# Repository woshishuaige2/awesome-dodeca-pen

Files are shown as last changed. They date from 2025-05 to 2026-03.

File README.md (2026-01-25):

# Dodeca Pen with Integrated Force and Motion Sensing

A smart stylus system that combines force sensing, inertial motion tracking, and computer vision for high-precision pen input. This project integrates a custom force-sensing PCB with a Seeed Studio Xiao nRF52840 Sense microcontroller, assembled into a 3D-printed pen body with computer vision tracking via ArUco markers.

---
## Clone Repository
Before continuing, clone the repository:
bash git clone https://github.com/woshishuaige2/awesome-dodeca-pen.git 
cd awesome-dodeca-pen

## 🔧 Tools and Equipment

| Component | Details |
| --- | --- |
| Development board | Seeed Studio XIAO nRF52840 Sense |
| Force sensor | Alps Alpine HSFPAR003A |
| Custom PCB | Use provided Gerber files (1.6mm thickness) |
| Printer filament | PLA (other hard plastics also acceptable) |
| Spring | 6.5 x 10 mm compression spring |
| Battery | 10440 lithium-ion battery |
| Wire | 22–24 AWG |
| Stylus nib | Wacom replacement nib or PLA substitute |
| 3D printer | Any (we used Bambu X1) |
| Hot air rework station  | For soldering force sensor |
| Soldering iron | For general electronics |
| Inkjet or laser printer | For printing ArUco/ChArUco markers |
| Smalll circular  magnet | For securing the dodeca lid | #TODO

---

## Microcontroller Code  #TODO
To upload the code to the development board:

Follow https://wiki.seeedstudio.com/XIAO_BLE/#software-setup to download the necessary software.
Open dodeca-pen-arduino in the Arduino IDE. 
Connect the board to your computer using a USB-C cable.
Click Tools > Board > Seeed nRF52 Boards > Seeed XIAO nRF52840 Sense.
Upload the code.

## 🛠️Build Step
1. Print all STL files in the ./STL folder using your 3D printer.

2. Solder the force sensor to the custom PCB. Align the top-left corner of the sensor (marked with a tiny circle) to the matching circle on the PCB.

3. Solder the PCB, battery, and development board together using wires, following the schematic below.
✂️ Make sure to cut each wire to the appropriate length so the components fit snugly inside the stylus body.
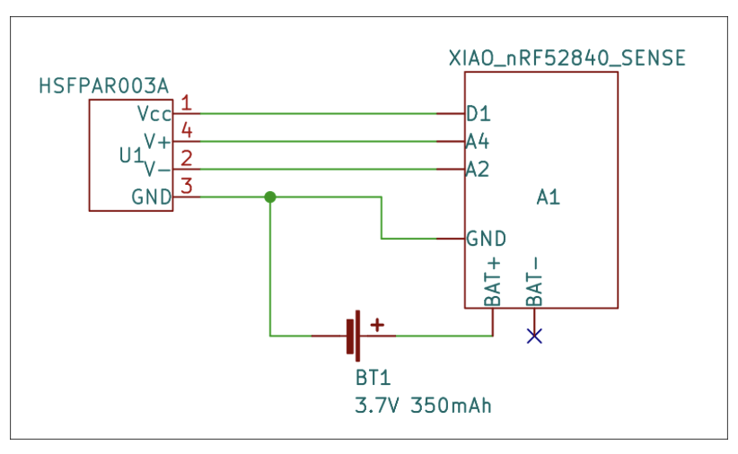
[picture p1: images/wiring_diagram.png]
Wiring diagram
Wiring diagram: 

4. Insert the assembled electronics (force sensor PCB, battery, and microcontroller) into the bottom half of the 3D-printed stylus body.
🕳️ Note: The body includes a hole for a switch to disconnect the battery during development. You can ignore this if not needed.

5. Find a small flat piece of metal or hard plastic, and glue it to the back of the 3D-printed nib base—specifically the part that makes contact with the force sensor.

6. Insert the nib into the 3D-printed nib base. Then fit the nib and compression spring into the front end of the stylus.
🧷 You may need to hold this assembly in place until the stylus is fully closed.

7. Slide the assembled stylus through the larger ring (07_d_ring.stl) until the ring rests at the rear of the stylus.

8. Attach the top half of the stylus, and secure it using the smaller ring (05_ring.stl).

9. Glue a small magnet into the magnet holder holes on both the dodeca ball lid and one half of the dodeca ball.

10. Insert the IMU into the first half of the dodeca ball.

11. Align the second half of the dodeca ball and secure both halves onto the stylus body using the larger ring.

12. Place the lid onto the dodeca ball so the two magnets snap together securely.

13. Print the ArUco markers from ./aruco_images/print.jpg at the correct scale. Carefully glue them onto each face of the dodeca ball, aligning them with the square cutouts.

14. Glue the markers to the stylus using a glue stick (or another adhesive).
🧭 Place the markers in the same order as labeled in the dodeca_stylus_half.stl file.

15. Finally, you'll also need a ChArUco board for camera calibration, which you can print using the pattern from markers/. You can either attach this to a flat board, or leave it on your desk. #TODO
---

## Software Step
👁️ Run the Computer Vision Module

This module detects ArUco/ChArUco markers on the dodeca ball and estimates the center point (and pose, if enabled) in real time.

0) Prerequisites

Python: 3.9–3.11 recommended

OpenCV (with contrib): required for ArUco

A camera: laptop webcam or USB camera

# From repo root
python -m venv .venv
source .venv/bin/activate   # Windows: .venv\Scripts\activate
pip install -r requirements.txt
# If needed (ArUco lives in contrib):
pip install opencv-contrib-python

Tip: If you already ran pip install -r requirements.txt, but detection fails with “module cv2.aruco not found”, install opencv-contrib-python explicitly as above. If you are missing any other libraries, please install manually.

1) (Recommended)🎯 Camera Calibration (Aruco/ChArUco)

  The camera must be calibrated before running tracking. This step creates:

  color_cam_matrix.npy – intrinsic matrix

  color_cam_dist.npy – distortion coefficients

  Both files are saved in the same folder as the script.

  1. Install dependencies
  Make sure you have the contrib build of OpenCV (for ArUco/ChArUco):

  pip install opencv-contrib-python

  2. Capture calibration images
  Print the provided ChArUco board and record 20–30 images at different angles, distances, and positions. Save them into a folder.

  3. Run calibration
  From the repo root:

  macOS/Linux:

  cd awesome_dodeca_pen/code/computer_vision/camera_calibration/Aruco_Calibration
  python calibrationAruco.py

  Windows (PowerShell):

  cd awesome_dodeca_pen\code\computer_vision\camera_calibration\Aruco_Calibration
  python .\calibrationAruco.py

  Make sure the script has Calibrate_camera = True when running calibration.

  4. Check results
  After successful calibration, you should see:

  color_cam_matrix.npy
  color_cam_dist.npy

  in the same folder. You can replace these two new files with the existing color_cam_matrix.npy and color_cam_dist.npy in ./Computer_vision/camera_matrix

2) Run the Dodeca Tracker (Live)
In ./Code/Computer_vision, run run.py by clicking the play button.
3) Running on Recorded Video (Optional)
In ./Code/Computer_vision/src, run offline_drawing_with_Dodeca.py by clicking the play button.

Inside Code folder:
    - ./Computer_vision has code similar to dodeca ball code, it uses computer vision to predict the center point of the dodecahedron.
    - ./IMU has code similar to DPOINT, with integrated code to capture Dodeca markers. You can think of this code as Dodeca+DPOINT, but the IMU prediction and Computer vision run on seperate threads
    - ./Kalman has code to process raw IMU sensor data after applying kalman filter on it. It is working now.

Run "pip3 install -r requirements.txt"

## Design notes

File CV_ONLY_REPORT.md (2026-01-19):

# Dodeca Pen: CV-Only Mode Verification Report

This report summarizes the successful implementation and verification of the **CV-only mode** for the Dodeca Pen system. The system was modified to bypass IMU input entirely while maintaining the EKF pipeline structure, using an offline video file for tracking.

## 1. Implementation Details

### 1.1 IMU Bypass
- **`Code/IMU/app/app.py`**: Modified to support a `--mode cv_only` flag. When enabled, the BLE acquisition process is not started, and the `QueueConsumer` only processes vision measurements.
- **`Code/IMU/app/filter.py`**: Updated the `update_camera` method to handle cases where no IMU history is available. In CV-only mode, the filter state is updated directly from vision measurements, with a prediction step to maintain covariance.

### 1.2 EKF Parameter Adjustments
To ensure vision measurements dominate the state:
- **Camera Noise**: Reduced to near-zero (`camera_noise_pos = 1e-9`, `camera_noise_or = 1e-7`).
- **Process Noise**: Increased to make the filter more responsive to camera updates without IMU guidance.

### 1.3 Offline Video Support
- The system uses the video file at `Code/Computer_vision/src/offline_test.mp4`.
- Headless mode is fully supported for environments without a display.

## 2. Verification Results

The system was run end-to-end for 60 seconds, processing the offline video file.

### 2.1 Tracking Performance
- **Frame Rate**: Averaged **8-12 FPS** during processing.
- **Detections**: Consistent ArUco marker detections (8-10 per frame).
- **Trajectory**: Successfully captured a continuous 3D trajectory of the pen tip.

### 2.2 Generated Outputs
The following files were generated and are available in the `Code/IMU/outputs/` directory:
- **`trajectory.csv`**: Raw pen-tip trajectory data (t, x, y, z).
- **`pentip_xy.png`**: 2D path plot of the pen tip.
- **`pentip_xyz.png`**: 3D trajectory plot of the pen tip.
- **`pentip_time.png`**: Time-series plot of X, Y, and Z positions.

## 3. How to Run

To replicate the results, use the following command:

```bash
cd Code/IMU
python3 main.py --mode cv_only --video /home/ubuntu/awesome-dodeca-pen/Code/Computer_vision/src/offline_test.mp4
```

After the run completes, generate the plots:

```bash
python3 plot_trajectory.py
```

## 4. Conclusion

The CV-only pipeline is now fully functional and verified. It provides a robust baseline for pen-tip tracking using only visual information, which can be used for comparison once IMU data is integrated in Stage 2.

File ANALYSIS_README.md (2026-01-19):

# Dodeca Pen Project Analysis: Documentation Package

**Date:** January 10, 2026  
**Prepared by:** Manus AI  
**Project:** awesome-dodeca-pen (woshishuaige2/awesome-dodeca-pen)

---

## Overview

This documentation package provides a comprehensive analysis of the Dodeca Pen project, including system architecture, execution flow, and modifications to enable offline video analysis. The analysis was conducted with thesis-level rigor, focusing on traceability and reproducibility.

## Documentation Files

### 1. **EXECUTION_TRACE.md**
A detailed step-by-step execution trace starting from `Code/IMU/main.py`. This document covers:
- Entry point and initialization sequence
- Process and thread architecture
- Data ingestion from IMU and camera
- Extended Kalman Filter data fusion pipeline
- Coordinate frames and transformations
- Real-time dependencies and coupling
- Key assumptions about geometry, sensors, and timing

**Use this document to:** Understand how the system works internally and trace the flow of data from sensors to visualization.

### 2. **OFFLINE_MODE_GUIDE.md**
A practical guide for enabling offline video analysis. This document covers:
- Summary of modifications made to the codebase
- Detailed explanation of changes in each file
- Step-by-step instructions for enabling offline mode
- Video format requirements and specifications
- Troubleshooting common issues

**Use this document to:** Set up and run the system with pre-recorded video files instead of a live camera.

### 3. **system_analysis.md**
A high-level overview of the system architecture. This document covers:
- Key components (IMU, CV, EKF, visualization)
- Data flow between components
- Modules dependent on live camera input
- Modification strategy for offline analysis

**Use this document to:** Get a quick understanding of the system architecture before diving into details.

### 4. **modifications.diff**
A Git diff file showing all code changes made to enable offline video support.

**Use this file to:** Review the exact changes made to the codebase or apply them to a different branch.

---

## Modified Files

The following files were modified to enable offline video support:

### 1. `Code/Computer_vision/run.py`
**Changes:**
- Added `video_file` parameter to `start()` and `main()` functions
- Added conditional logic to use `cv2.VideoCapture(video_file)` when `video_file` is specified
- Preserved all original live camera functionality

**Lines modified:** 132-158, 242-252

### 2. `Code/IMU/app/app.py`
**Changes:**
- Added `OFFLINE_VIDEO_FILE` configuration variable in `main()` function
- Passed this variable to the CV thread when starting it
- Added comments explaining how to enable offline mode

**Lines modified:** 466-478

---

## Phase 1: Code Understanding (Completed)

### What Data is Being Ingested

1. **IMU Data (via BLE):**
   - **Accelerometer:** 3-axis, ~100-200 Hz, in m/s²
   - **Gyroscope:** 3-axis, ~100-200 Hz, in rad/s
   - **Pressure:** Single value, ~100-200 Hz, normalized [0, 1]
   - **Source:** Arduino-based IMU in the pen, transmitted via Bluetooth Low Energy

2. **Camera Data (via OpenCV):**
   - **RGB Frames:** 640x480 or higher, ~10-30 fps
   - **ArUco Markers:** Detected in each frame
   - **Pose Estimate:** 6-DoF (position + orientation), ~10-30 Hz
   - **Source:** USB webcam or video file

3. **Timestamps:**
   - IMU timestamps are currently unused (set to 0)
   - Camera timestamps are generated using `time.time()` when pose is published
   - EKF uses a fixed time step `dt` for prediction

### How Data Flows Through the Pipeline

```
┌─────────────────┐         ┌─────────────────┐
│   Dodeca Pen    │         │   USB Camera    │
│   (Hardware)    │         │   (or Video)    │
└────────┬────────┘         └────────┬────────┘
         │ BLE                       │ USB/File
         ▼                           ▼
┌─────────────────┐         ┌─────────────────┐
│  monitor_ble    │         │     run.py      │
│   (Process)     │         │    (Thread)     │
└────────┬────────┘         └────────┬────────┘
         │ ble_queue                 │ object_pose
         │                           │ (global var)
         ▼                           ▼
┌────────────────────────────────────────────┐
│          QueueConsumer (Thread)            │
│  ┌──────────────────────────────────────┐  │
│  │   Extended Kalman Filter (EKF)       │  │
│  │  - Prediction: IMU data (~100 Hz)    │  │
│  │  - Correction: Camera data (~20 Hz)  │  │
│  │  - Smoothing: RTS backward pass      │  │
│  └──────────────────────────────────────┘  │
└────────────────┬───────────────────────────┘
                 │ new_data signal
                 ▼
         ┌───────────────┐
         │ CanvasWrapper │
         │  (VisPy 3D)   │
         └───────────────┘
```

### Key Assumptions

1. **Geometry:**
   - IMU is assumed to be at the pen tip (simplification)
   - Pen is a rigid body with no deformation
   - Tip offset from dodecahedron center is known and constant

2. **Sensors:**
   - IMU and camera are calibrated
   - ArUco marker positions on the pen are known
   - At least 2 markers must be visible for pose estimation

3. **Timing:**
   - IMU sends data at a roughly constant rate
   - Camera has a small, constant delay (compensated by filter)
   - BLE packet loss is negligible

4. **Environment:**
   - Camera is stationary
   - Lighting is sufficient for marker detection
   - All motion is relative to the camera frame

### Coordinate Frames

1. **Camera Frame:** Origin at camera optical center, X right, Y down, Z forward (OpenCV convention)
2. **Pen Body Frame:** Origin at dodecahedron center, aligned with pen structure
3. **IMU Frame:** Origin at IMU sensor location, aligned with IMU chip axes
4. **Pen Tip Frame:** Origin at physical pen tip, same axes as body frame

### Real-Time Dependencies

- **Tight Coupling:** CV thread runs in the same process as main app, allowing direct memory access
- **No IPC Overhead:** Camera data is read directly from a global variable, not through a queue
- **Latency Compensation:** EKF maintains a history buffer and applies smoothing to account for camera delay
- **Shutdown Coordination:** Shared flag (`cv_shutdown_requested`) coordinates graceful shutdown

---

## Phase 2: Offline Analysis Modifications (Completed)

### Sections Enabling Live CV Window and Camera Capture

1. **`Code/Computer_vision/run.py::start()` (Line 140):**
   ```python
   cap = cv2.VideoCapture(cam_index)  # Opens live camera
   ```

2. **`Code/Computer_vision/run.py::start()` (Lines 160-164):**
   ```python
   if not headless:
       w, h = int(cap.get(3)), int(cap.get(4))
       cv2.namedWindow("RGB-D Live Stream", cv2.WINDOW_NORMAL)
       cv2.resizeWindow("RGB-D Live Stream", w, h)
       cv2.moveWindow("RGB-D Live Stream", 20, 20)
   ```

3. **`Code/Computer_vision/run.py::start()` (Lines 212-216):**
   ```python
   if not headless:
       cv2.imshow("RGB-D Live Stream", rgb)
       if cv2.waitKey(1) & 0xFF == ord("q"):
           _request_shutdown()
           break
   ```

4. **`Code/IMU/app/app.py::main()` (Lines 467-478):**
   ```python
   cv_thread = threading.Thread(
       target=cv_run.main, 
       kwargs={"headless": False, "cam_index": 0, "video_file": OFFLINE_VIDEO_FILE}, 
       daemon=True
   )
   cv_thread.start()
   ```

### Modifications Made

**No code was deleted.** All modifications are additive and preserve the original functionality:

1. **Added `video_file` parameter** to `run.py::start()` and `run.py::main()`
2. **Added conditional logic** to use video file when specified, otherwise use live camera
3. **Added `OFFLINE_VIDEO_FILE` variable** in `app.py::main()` for easy configuration

### How to Enable Offline Mode

1. **Prepare your video file:**
   - Format: MP4 (H.264 codec recommended)
   - Content: Dodeca Pen with ArUco markers clearly visible
   - Recommended filename: `offline_test.mp4`

2. **Place the video file:**
   - Recommended location: `Code/Computer_vision/offline_test.mp4`
   - Or use an absolute path

3. **Modify `Code/IMU/app/app.py` line 471:**
   ```python
   # Change from:
   OFFLINE_VIDEO_FILE = None
   
   # To:
   OFFLINE_VIDEO_FILE = "offline_test.mp4"
   ```

4. **Run the application:**
   ```bash
   cd Code/IMU
   python main.py
   ```

### Expected Placeholder Video

**Filename:** `offline_test.mp4`  
**Location:** `Code/Computer_vision/offline_test.mp4`

**Format Requirements:**
- **Container:** MP4, AVI, MOV, or MKV
- **Codec:** H.264 (for MP4) or other OpenCV-compatible codec
- **Resolution:** 640x480 or higher
- **Frame Rate:** 30 fps or higher
- **Content:** Dodeca Pen with ArUco markers clearly visible throughout

**Recording Tips:**
- Ensure good lighting (avoid shadows on markers)
- Keep markers in focus
- Move the pen slowly to avoid motion blur
- Ensure at least 2 markers are visible in most frames
- Use the same camera that was used for calibration (or recalibrate)

---

## Next Steps

1. **Record a test video** showing the Dodeca Pen with ArUco markers
2. **Name the video** `offline_test.mp4`
3. **Place it** in `Code/Computer_vision/`
4. **Update** line 471 in `Code/IMU/app/app.py` to enable offline mode
5. **Run** the application and verify the system processes the video correctly

---

## Additional Notes

### Optimization Opportunities (Not Implemented)

The following optimizations were deliberately **not** implemented to keep changes minimal:

1. **Frame rate control:** The system processes video frames as fast as possible. For more accurate timing, you could add frame rate control based on the video's metadata.

2. **Video looping control:** OpenCV automatically loops videos. You could add logic to stop after one pass.

3. **Progress indicator:** You could display the current frame number and total frames.

4. **Multiple video support:** You could add a command-line interface to specify the video file without editing code.

These can be added later if needed, but the current implementation focuses on minimal, non-destructive changes.

### Testing Recommendations

1. **Test with live camera first** to ensure the system works correctly
2. **Record a short test video** (10-30 seconds) with good marker visibility
3. **Verify offline mode** processes the video and tracks markers correctly
4. **Compare results** between live and offline modes to ensure consistency

### Troubleshooting

See `OFFLINE_MODE_GUIDE.md` for detailed troubleshooting steps.

---

## Contact and Collaboration

This analysis was prepared to facilitate thesis-level research collaboration. All documentation emphasizes:

- **Rigor:** Detailed technical analysis with precise terminology
- **Traceability:** Clear references to specific files and line numbers
- **Reproducibility:** Step-by-step instructions for replicating the setup

For questions or issues, refer to the specific documentation files or examine the code with the provided line number references.

---

**End of Analysis Package**

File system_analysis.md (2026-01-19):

# Dodeca Pen Project: System Analysis

This document provides a detailed analysis of the Dodeca Pen project, focusing on its system architecture, data flow, and key components. The analysis is based on the code in the `woshishuaige2/awesome-dodeca-pen` repository.

## 1. High-Level System Overview

The Dodeca Pen system is designed to track the 3D position and orientation of a custom-built pen-like device. It achieves this by fusing data from two primary sources: an Inertial Measurement Unit (IMU) embedded in the pen and an external camera that tracks ArUco markers on the pen's body. The system is implemented in Python and uses a multi-process and multi-threaded architecture to handle real-time data acquisition and processing.

### Key Components:

*   **IMU Data Acquisition:** A dedicated process (`monitor_ble.py`) connects to the pen via Bluetooth Low Energy (BLE) to receive real-time IMU data (accelerometer, gyroscope, and pressure).
*   **Computer Vision (CV) Tracking:** A separate thread (`run.py`) uses a standard webcam to detect ArUco markers on the pen. It estimates the pen's 6-DoF pose (position and orientation) relative to the camera.
*   **Data Fusion:** An Extended Kalman Filter (EKF) implemented in `filter.py` fuses the high-frequency IMU data with the lower-frequency but more stable CV pose estimates. This corrects for IMU drift and provides a smooth and accurate track of the pen's tip.
*   **3D Visualization:** The system uses the VisPy library to provide a real-time 3D visualization of the pen's movement and the path it draws.

## 2. Data Flow and Execution Trace

The execution of the Dodeca Pen application starts with `Code/IMU/main.py`, which immediately calls the `main()` function in `Code/IMU/app/app.py`. The following is a step-by-step trace of the execution flow:

1.  **Initialization:** The `main()` function in `app.py` initializes the PyQt6 application, creates a VisPy canvas for visualization (`CanvasWrapper`), and sets up several multiprocessing queues for inter-process communication (`tracker_queue`, `ble_queue`, `ble_command_queue`).

2.  **Process/Thread Creation:** The `main()` function then spawns the following processes and threads:
    *   **BLE Process:** A `multiprocessing.Process` is started to run the `monitor_ble()` function. This process connects to the "DPOINT" BLE device, receives IMU data packets, unpacks them into `StylusReading` objects, and puts them into the `ble_queue`.
    *   **CV Thread:** A `threading.Thread` is started to run the `main()` function from `Code/Computer_vision/run.py`. This thread continuously captures frames from the camera, detects ArUco markers, and estimates the pen's pose. The pose is stored in a global variable `object_pose` within the `run.py` module.
    *   **Data Consumer Thread:** A `QThread` is created to run the `QueueConsumer` object. This is the heart of the data fusion logic.

3.  **Data Fusion in `QueueConsumer`:** The `run_queue_consumer()` method of the `QueueConsumer` runs in a loop and performs the following actions:
    *   **IMU Data Processing:** It retrieves `StylusReading` objects from the `ble_queue` and uses them to update the EKF via the `_filter.update_imu()` method.
    *   **CV Data Processing:** It calls `dodeca_bridge.make_ekf_measurements()`, which reads the `object_pose` from the `run.py` module. The pose data is then used to update the EKF via the `_filter.update_camera()` method. This step also triggers a smoothing algorithm to correct past state estimates.
    *   **Data Emission:** The `QueueConsumer` emits a `new_data` signal containing either `StylusUpdateData` (from the IMU) or `CameraUpdateData` (from the CV system). This signal is connected to the `CanvasWrapper` to update the 3D visualization.

4.  **Visualization:** The `CanvasWrapper` receives the `new_data` signal and updates the 3D scene, including the position and orientation of the pen model and the drawn trail.

## 3. Modules Dependent on Live Camera Input

The following modules and code sections are directly involved in handling the live camera feed:

*   **`Code/Computer_vision/run.py`:** This is the primary module responsible for camera interaction. The `start()` function initializes the camera capture using `cv2.VideoCapture(cam_index)`. The main loop of this function reads frames from the camera, performs marker detection, and displays the live video feed in a window if not running in headless mode.
*   **`Code/IMU/app/app.py`:** The `main()` function in this file is responsible for starting the CV thread: `cv_thread = threading.Thread(target=cv_run.main, kwargs={"headless": False, "cam_index": 0}, daemon=True)`. This line directly initiates the live camera capture.

## 4. Modification for Offline Analysis

To facilitate offline analysis and collaboration, the live camera feed can be replaced with a pre-recorded video file. This requires the following modifications:

1.  **Identify and Comment Out Live Camera Logic:** The primary code to modify is in `Code/Computer_vision/run.py`. The line `cap = cv2.VideoCapture(cam_index)` should be commented out and replaced with `cap = cv2.VideoCapture("offline_test.mp4")`.

2.  **Specify Placeholder Video:** The placeholder video file should be named `offline_test.mp4` and placed in the `Code/Computer_vision/` directory. The video should be a standard MP4 file containing a recording of the Dodeca Pen with its ArUco markers clearly visible.

By making these changes, the system will process the video file frame by frame, allowing for reproducible analysis of the tracking and fusion algorithms without the need for a live camera setup.

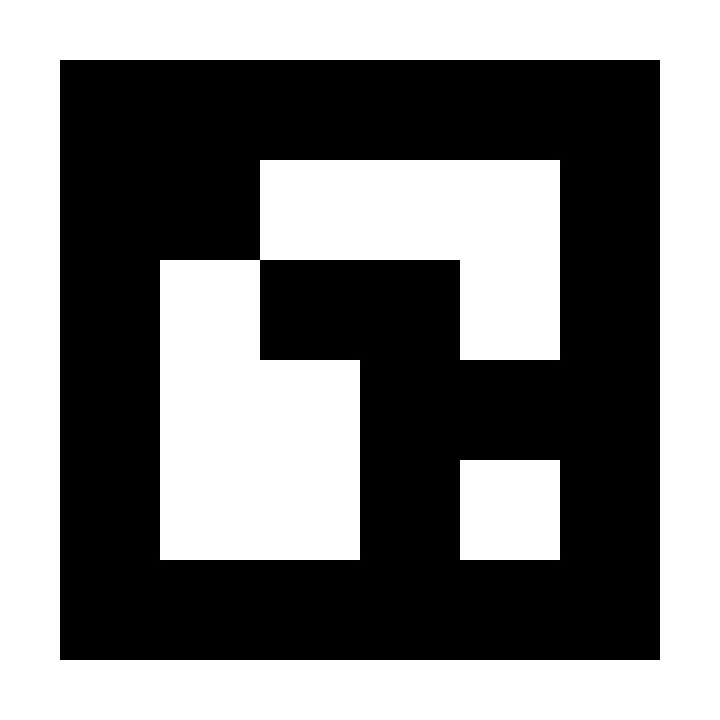
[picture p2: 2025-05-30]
Code/Computer_vision/dodecapen_assets/aruco_images_mip_maps/res_600_5.jpg

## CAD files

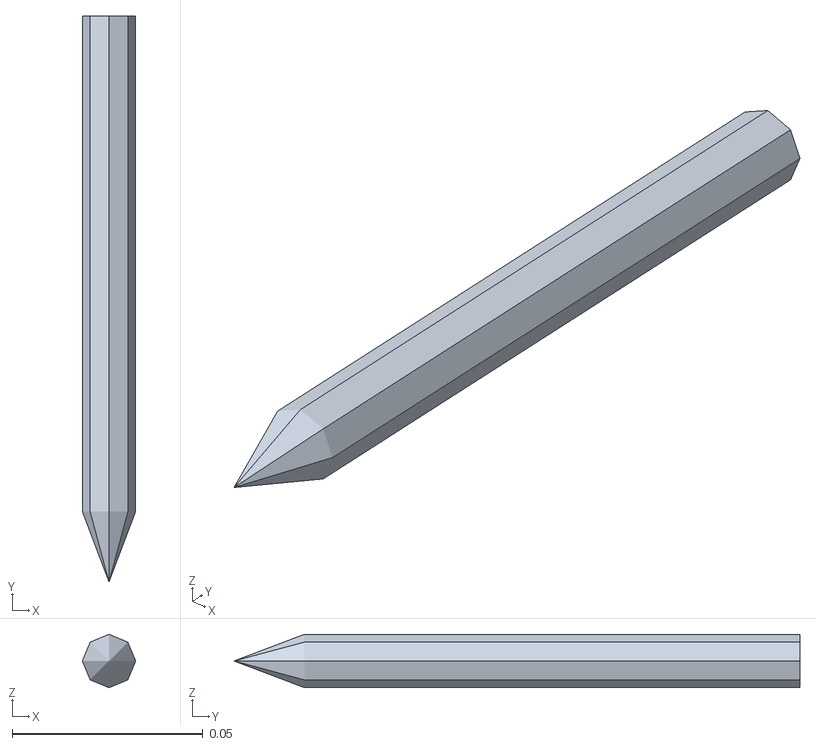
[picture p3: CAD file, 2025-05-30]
Code/IMU/app/mesh/pen.obj
0.014 x 0.148 x 0.014

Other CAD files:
Code/IMU/app/mesh/pen.blend

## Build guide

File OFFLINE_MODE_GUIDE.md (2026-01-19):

# Offline Video Mode: Modification Guide

This document explains the modifications made to enable offline video analysis in the Dodeca Pen project. These changes allow you to replace the live camera feed with a pre-recorded video file for reproducible research and easier collaboration.

## Summary of Changes

The modifications are **minimal and non-destructive**. No code has been deleted; instead, the system now supports both live camera and offline video modes through a simple parameter change.

## Modified Files

### 1. `Code/Computer_vision/run.py`

**Changes:**
- Added a new parameter `video_file` to the `start()` and `main()` functions
- When `video_file` is specified, the system uses `cv2.VideoCapture(video_file)` instead of `cv2.VideoCapture(cam_index)`
- All original live camera logic is preserved and used when `video_file=None`

**Key Code Section (Lines 132-158):**
```python
def start(headless: bool = True, cam_index: int = 0, video_file: str = None) -> None:
    """
    Main vision loop.
    
    Args:
        headless: If True, runs without displaying the video window
        cam_index: Camera index for live capture (ignored if video_file is specified)
        video_file: Path to offline video file. If specified, uses this instead of live camera.
    """
    global object_pose

    # >>> MODIFICATION: Support offline video input <<<
    if video_file is not None:
        print(f"[CV] Using offline video file: {video_file}")
        cap = cv2.VideoCapture(video_file)
    else:
        # >>> ORIGINAL: Live camera capture <<<
        cap = cv2.VideoCapture(cam_index)
    
    if not cap.isOpened():
        if video_file is not None:
            print(f"[CV] Could not open video file: {video_file}")
        else:
            print(f"[CV] Could not open camera index {cam_index}")
        return
```

### 2. `Code/IMU/app/app.py`

**Changes:**
- Added a configuration variable `OFFLINE_VIDEO_FILE` in the `main()` function (line 471)
- This variable is passed to the CV thread when it starts
- Setting `OFFLINE_VIDEO_FILE = None` uses live camera (default)
- Setting `OFFLINE_VIDEO_FILE = "path/to/video.mp4"` uses offline video

**Key Code Section (Lines 466-478):**
```python
# --- NEW: launch the CV loop in-process so the bridge can see object_pose ---
# >>> MODIFICATION: Support offline video input <<<
# To use offline video, set video_file parameter to the path of your video file
# Example: video_file="offline_test.mp4" or video_file="/path/to/your/video.mp4"
# Set to None to use live camera (default behavior)
OFFLINE_VIDEO_FILE = None  # <<< CHANGE THIS to enable offline mode

cv_thread = threading.Thread(
    target=cv_run.main, 
    kwargs={"headless": False, "cam_index": 0, "video_file": OFFLINE_VIDEO_FILE}, 
    daemon=True
)
cv_thread.start()
```

## How to Enable Offline Mode

### Step 1: Prepare Your Video File

Record a video of the Dodeca Pen with ArUco markers clearly visible. The video should be in a standard format (MP4, AVI, MOV, etc.) that OpenCV can read.

**Recommended Video Specifications:**
- **Format:** MP4 (H.264 codec)
- **Resolution:** 640x480 or higher
- **Frame Rate:** 30 fps or higher
- **Duration:** As needed for your analysis
- **Content:** Dodeca Pen with ArUco markers clearly visible throughout the video

### Step 2: Place the Video File

You have two options:

**Option A: Relative Path (Recommended)**
Place your video file in the `Code/Computer_vision/` directory and use a relative filename:
```
awesome-dodeca-pen/
├── Code/
│   ├── Computer_vision/
│   │   ├── offline_test.mp4  ← Place your video here
│   │   └── run.py
│   └── IMU/
│       └── app/
│           └── app.py
```

**Option B: Absolute Path**
Place your video file anywhere and use the full path.

### Step 3: Modify `app.py`

Open `Code/IMU/app/app.py` and locate line 471. Change:

```python
OFFLINE_VIDEO_FILE = None  # Live camera mode
```

To one of the following:

**For relative path:**
```python
OFFLINE_VIDEO_FILE = "offline_test.mp4"
```

**For absolute path:**
```python
OFFLINE_VIDEO_FILE = "/home/user/videos/my_recording.mp4"
```

**For relative path from Computer_vision directory:**
```python
OFFLINE_VIDEO_FILE = str(Path(__file__).resolve().parents[2] / "Computer_vision" / "offline_test.mp4")
```

### Step 4: Run the Application

Run the application as usual:
```bash
cd Code/IMU
python main.py
```

The system will now process the video file instead of the live camera feed. You should see a message in the console:
```
[CV] Using offline video file: offline_test.mp4
```

## Switching Back to Live Camera Mode

To return to live camera mode, simply change the line back to:
```python
OFFLINE_VIDEO_FILE = None
```

## Expected Placeholder Video Filename

If you follow the recommended approach, the expected filename is:

**`offline_test.mp4`**

Place this file in the `Code/Computer_vision/` directory.

## Video Format Requirements

The video file should be compatible with OpenCV's `cv2.VideoCapture()`. Most common video formats are supported, including:

- **MP4** (H.264, MPEG-4)
- **AVI** (various codecs)
- **MOV** (QuickTime)
- **MKV** (Matroska)

**Important Notes:**
- Ensure the video codec is installed on your system
- For best compatibility, use MP4 with H.264 codec
- The video should show the Dodeca Pen with ArUco markers clearly visible
- Lighting conditions should be similar to your live camera setup

## Verification

To verify the modification is working correctly:

1. Check the console output for the message: `[CV] Using offline video file: ...`
2. The CV window should display frames from your video file
3. The system should track ArUco markers and update the 3D visualization as usual
4. The video will loop continuously (OpenCV behavior) or you can modify the code to stop after one pass

## Troubleshooting

**Problem:** "Could not open video file"
- **Solution:** Check that the file path is correct and the file exists
- **Solution:** Verify the video format is supported by OpenCV
- **Solution:** Try using an absolute path instead of a relative path

**Problem:** Video plays but no markers are detected
- **Solution:** Ensure the ArUco markers are clearly visible in the video
- **Solution:** Check that the lighting and focus are adequate
- **Solution:** Verify the camera calibration parameters match the camera used to record the video

**Problem:** Video plays too fast or too slow
- **Solution:** The system processes frames as fast as possible. If timing is critical, you may need to add frame rate control in the `start()` function

## Next Steps

Once you have recorded a compatible video file:
1. Name it `offline_test.mp4` (or update the path in `app.py`)
2. Place it in the `Code/Computer_vision/` directory
3. Update line 471 in `Code/IMU/app/app.py` as described above
4. Run the application and verify the offline mode is working

The system will then process your video file frame by frame, allowing for reproducible analysis without requiring a live camera setup.

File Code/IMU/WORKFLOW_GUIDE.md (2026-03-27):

# Complete Workflow Guide: Offline Recording and Processing

This guide explains the new workflow for recording and processing pen tracking data with improved CV quality.

## Problem Summary

The previous `record_raw_data_filtered.py` performed real-time CV processing during recording, which resulted in noisy trajectories. Analysis showed that while frame drops were minimal (0.1%), the real-time CV detection quality was inferior to offline processing.

## Solution

Separate recording from processing:
1. **Record** IMU data + raw video (no CV processing)
2. **Process** video offline using proven CV pipeline
3. **Merge** IMU and CV data with proper synchronization
4. **Analyze** using existing `compare_workflows.py`

## New Workflow

### Step 1: Record IMU Data and Video

Use the new `record_imu_and_video.py` script:

```bash
cd Code/IMU
python record_imu_and_video.py --output outputs/recording --camera 0
```

**What it does:**
- Records IMU data from BLE device
- Records raw video from camera (no CV processing)
- Saves to separate files:
  - `outputs/recording/imu_data.json` - IMU readings
  - `outputs/recording/video.mp4` - Raw video
  - `outputs/recording/metadata.json` - Recording metadata

**When to stop:**
- Press `Ctrl+C` when finished recording
- Recommended: Record 10-15 seconds of pen movement

### Step 2: Process Video to Extract CV Data

Use the new `process_video_to_cv_data.py` script:

```bash
cd Code/IMU
python process_video_to_cv_data.py outputs/recording/video.mp4 --output outputs/recording/cv_data.json
```

**What it does:**
- Processes video frame-by-frame using the same CV pipeline as offline mode
- Applies One-Euro filtering for smooth trajectories
- Extracts dodecahedron center position and orientation
- Saves CV readings in my_data.json format

**Options:**
- `--no-filter` - Disable One-Euro filtering (not recommended)

### Step 3: Merge IMU and CV Data

Use the new `merge_imu_cv_data.py` script:

```bash
cd Code/IMU
python merge_imu_cv_data.py outputs/recording/imu_data.json outputs/recording/cv_data.json --output outputs/my_data.json
```

**What it does:**
- Synchronizes IMU and CV timestamps
- Aligns both streams to start at first CV detection
- Creates unified `my_data.json` in the format expected by `compare_workflows.py`

**Synchronization methods:**
- `--sync first_detection` (default) - Align at first CV marker detection
- `--sync manual --offset X.X` - Manual offset in seconds (CV - IMU)

### Step 4: Calibrate IMU Axis Alignment

Use one or more merged stationary recordings captured in clearly different pen orientations:

```bash
cd Code/IMU
python calibrate_imu_alignment.py outputs/calib_pose_1.json outputs/calib_pose_2.json outputs/calib_pose_3.json
```

**What it does:**
- Estimates a fixed IMU-to-body rotation from stationary gravity observations
- Saves the calibration to `calibration/imu_to_body.json`
- Prints a warning if you only provide one pose, because that only constrains gravity alignment and not the full 3D yaw relationship

**Recommended calibration data:**
- Record `6 to 10` stationary batches
- Hold each pose for `5 to 10 s`
- Make the orientations clearly different
- Keep the camera fixed during the calibration session and the validation run, because the calibration also estimates gravity in the camera frame
- Treat large residuals as a bad calibration; low residuals mean the stationary poses agree under one rigid IMU-to-body transform

### Step 5: Analyze Results

Use the existing `compare_workflows.py`:

```bash
cd Code/IMU
python compare_workflows.py outputs/my_data.json
```

**What it does:**
- Generates comparison plots for:
  - CV Only (Raw)
  - Standard EKF (Coupled)
  - Decoupled EKF (Proposed)
- Saves visualization to `outputs/comparison.png`
- Automatically loads `calibration/imu_to_body.json` if it exists

## Complete Example

```bash
# Navigate to IMU directory
cd /path/to/awesome-dodeca-pen/Code/IMU

# Step 1: Record (press Ctrl+C to stop)
python record_imu_and_video.py --output outputs/recording

# Step 2: Process video
python process_video_to_cv_data.py outputs/recording/video.mp4 --output outputs/recording/cv_data.json

# Step 3: Merge data
python merge_imu_cv_data.py outputs/recording/imu_data.json outputs/recording/cv_data.json --output outputs/my_data.json

# Step 4: Calibrate IMU alignment
python calibrate_imu_alignment.py outputs/calib_pose_1.json outputs/calib_pose_2.json outputs/calib_pose_3.json

# Step 5: Analyze
python compare_workflows.py outputs/my_data.json
```

## Advantages of New Workflow

1. **Better CV Quality**: Uses proven offline CV pipeline that produces clean trajectories
2. **No Real-time Overhead**: Recording doesn't compete with CV processing for resources
3. **Reproducible**: Can re-process same video with different parameters
4. **Debuggable**: Can inspect raw video and intermediate results
5. **Flexible**: Can apply different filters or CV algorithms offline

## Troubleshooting

### Low CV Detection Rate

If `process_video_to_cv_data.py` reports low detection rate (<50%):
- Check lighting conditions during recording
- Ensure markers are clearly visible
- Avoid rapid movements that cause motion blur
- Check camera focus and exposure settings

### Synchronization Issues

If trajectories don't align properly:
- Try manual synchronization: `--sync manual --offset X.X`
- Check metadata.json for timing information
- Verify both IMU and CV have data in overlapping time range

### Video Quality Issues

If video quality is poor:
- Increase camera resolution in `record_imu_and_video.py`
- Improve lighting conditions
- Use a higher quality camera
- Reduce camera auto-exposure/auto-focus

## File Structure

```
outputs/
├── recording/
│   ├── imu_data.json      # Raw IMU readings
│   ├── video.mp4          # Raw video recording
│   ├── cv_data.json       # Processed CV readings
│   └── metadata.json      # Recording metadata
├── my_data.json           # Merged IMU + CV data
└── comparison.png         # Analysis visualization
```

## Migration from Old Workflow

**Old workflow:**
```bash
python record_raw_data_filtered.py --output outputs/my_data.json
python compare_workflows.py outputs/my_data.json
```

**New workflow:**
```bash
python record_imu_and_video.py --output outputs/recording
python process_video_to_cv_data.py outputs/recording/video.mp4 --output outputs/recording/cv_data.json
python merge_imu_cv_data.py outputs/recording/imu_data.json outputs/recording/cv_data.json --output outputs/my_data.json
python compare_workflows.py outputs/my_data.json
```

The new workflow has more steps but produces significantly better results.

## Technical Details

### Timestamp Alignment

The merge script uses `first_detection` method by default:
1. Finds first IMU reading timestamp: `t_imu_0`
2. Finds first CV detection timestamp: `t_cv_0`
3. Uses `max(t_imu_0, t_cv_0)` as sync point
4. Aligns all timestamps relative to sync point

This ensures both streams have valid data at t=0.

### One-Euro Filter Parameters

The CV processing uses One-Euro filter with default parameters:
- `min_cutoff`: 1.0 Hz
- `beta`: 0.007
- `d_cutoff`: 1.0 Hz

These can be adjusted in `process_video_to_cv_data.py` if needed.

### Data Format Compatibility

The merged `my_data.json` maintains full compatibility with existing tools:
- `compare_workflows.py` - No changes needed
- Field names match original format
- Metadata includes all required parameters

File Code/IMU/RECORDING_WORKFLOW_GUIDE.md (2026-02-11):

# Dodeca Pen Recording and Analysis Workflow Guide

## Overview

This guide explains the complete workflow for recording pen sketching data and analyzing it through different EKF strategies. The workflow includes **integrated One-Euro filtering** during recording to produce clean, smooth CV trajectories.

---

## Important: Coordinate System

**What Computer Vision Detects:**
- CV tracks ArUco markers on the dodecahedron and outputs the **DODECAHEDRON CENTER** position and orientation
- The recorded data contains `center_pos_cam` which is this detected center position in the camera frame

**Key Offsets (defined in body frame):**
- `CENTER_TO_TIP_BODY` = [0, 137.5mm, -82.1mm] - offset from dodeca center to pen tip
- `IMU_OFFSET_BODY` = [0, 0, 0] - offset from dodeca center to IMU (currently simplified as zero)

**Current Simplification:**
- We assume the IMU is located at the dodecahedron center (IMU_OFFSET_BODY = [0,0,0])
- This means the filter tracks the dodeca center position, not the actual IMU or tip position
- For accurate tip tracking, the workflow applies the CENTER_TO_TIP_BODY offset

---

## File Structure and Purpose

| File | Purpose |
|---|---|
| **record_raw_data_filtered.py** | **[RECOMMENDED]** Records both CV and IMU data with One-Euro filter applied to CV readings in real-time. Produces clean trajectories. |
| **record_raw_data.py** | Records raw, unfiltered CV and IMU data. Use only if you want to test without filtering. |
| **playback_raw_data.py** | Replays recorded data through the EKF and outputs a CSV trajectory file. |
| **plot_trajectory.py** | (Optional) Generates XY plot, 3D plot, and time series plots using "decoupled EKF". |
| **compare_workflows.py** | Compares three EKF strategies (CV only, Standard EKF, Decoupled EKF) and generates comparative visualizations. |

---

## Step-by-Step Workflow

### Step 1: Record Data with Filtering

Use the **new filtered recording script** to capture clean CV data:

```bash
cd Code/IMU
python3 record_raw_data_filtered.py --output outputs/my_data.json
```

**What this does:**
- Connects to your pen via BLE and captures IMU data (accel, gyro, pressure)
- Captures computer vision pose estimates from the camera
- **Applies One-Euro filtering** to the CV position and orientation in real-time
- Saves both streams to `outputs/my_data.json`

**During recording:**
- You'll see status messages showing marker detection and sample counts
- Draw your rectangle (or any shape) on the sketching plane
- Lift the pen to demonstrate the Z-axis motion
- Press `Ctrl+C` to stop and save

**Expected output:**
```
[Recorder] IMU recording started.
[Recorder] CV recording started with One-Euro filtering.
=== Recording Started ===
Press Ctrl+C to stop recording

[12:34:56] Marker: DETECTED | Pos: (0.123, 0.456, 0.789)
[Recorder] IMU: received 100 samples
[Recorder] CV: received 50 filtered samples
...
^C
[Main] Stopping...
[Recorder] Data saved to outputs/my_data.json
[Recorder] Recorded 509 IMU and 420 filtered CV samples.
```

---

### Step 2: Compare EKF Strategies

Run the comparison script to test all three workflows:

```bash
cd Code/IMU
python3 compare_workflows.py
```

**What this does:**
- Loads `outputs/my_data.json`
- Runs three different EKF strategies:
  1. **CV Only (Raw):** Uses only the filtered CV data, no IMU fusion
  2. **Standard EKF (Coupled):** Fuses CV position + orientation with IMU (7D updates)
  3. **Decoupled EKF (Proposed):** Fuses CV position only with IMU (3D updates, orientation from IMU only)
- Generates `outputs/workflow_comparison.png` with 4 subplots

**Expected output:**
```
Running CV Only workflow...
Running Standard EKF workflow...
Running Decoupled EKF workflow...
Workflow CV Only (Raw): 420 points
  CV Only (Raw) - X mean: 0.1234, Y mean: 0.5678, Z mean: 0.5079
Workflow Standard EKF (Coupled): 420 points
  Standard EKF (Coupled) - X mean: 0.1235, Y mean: 0.5679, Z mean: 0.5008
Workflow Decoupled EKF (Proposed): 420 points
  Decoupled EKF (Proposed) - X mean: 0.1233, Y mean: 0.5677, Z mean: 0.4955
Comparison plot saved to ./outputs/workflow_comparison.png
```

---

### Step 3: Interpret the Results

Open `outputs/workflow_comparison.png` to see four plots:

#### 1. **3D Pen-Tip Trajectory** (Top-Left)
Shows the full 3D motion of the pen tip. You should see:
- A rectangular path in the XY plane
- An upward motion in Z when you lifted the pen

#### 2. **XY Plane (Top View)** (Top-Right)
Shows the top-down view of your sketching. The rectangle should be clearly visible here.
- **CV Only** may show some jitter
- **Standard EKF** should be smoother but may have "wandering"
- **Decoupled EKF** should be the smoothest and most stable

#### 3. **Z-Axis (Absolute Height)** (Bottom-Left)
Shows the pen's height over time. You should see:
- A relatively flat region while drawing the rectangle
- A clear upward trend when you lifted the pen
- **Decoupled EKF** should show the cleanest lift-off

#### 4. **Z-Axis Jitter (High-pass filtered)** (Bottom-Right)
Shows only the high-frequency noise in the Z-axis.
- **CV Only** will be the most noisy
- **Standard EKF** will be smoother but still show some vibration
- **Decoupled EKF** should be the flattest (least jitter)

---

## Key Differences Between Workflows

| Workflow | CV Position | CV Orientation | IMU Accel/Gyro | Result |
|---|---|---|---|---|
| **CV Only** | ✅ Used | ✅ Used | ❌ Ignored | High jitter, no sensor fusion |
| **Standard EKF** | ✅ Fused (7D) | ✅ Fused (7D) | ✅ Fused | Smooth but orientation jitter propagates to position |
| **Decoupled EKF** | ✅ Fused (3D) | ❌ Ignored | ✅ Fused (orientation only) | Best stability, orientation from IMU only |

---

## Troubleshooting

### Problem: "Marker: NOT DETECTED" during recording
**Solution:**
- Ensure good lighting on the dodecahedron markers
- Keep the pen within the camera's field of view
- Check that the camera is connected and working

### Problem: Very few CV readings recorded
**Solution:**
- Make sure the dodecahedron is clearly visible throughout the recording
- Move the pen more slowly to ensure consistent detection
- Check camera focus and exposure settings

### Problem: Trajectory doesn't look like a rectangle
**Solution:**
- The One-Euro filter should now produce clean trajectories
- If still noisy, check that you're using `record_raw_data_filtered.py` (not the old `record_raw_data.py`)
- Ensure you drew a clear rectangle during recording

### Problem: "Array must not contain infs or NaNs" error
**Solution:**
- This was caused by the old post-processing filter
- The new integrated filter in `record_raw_data_filtered.py` should not have this issue
- If you still see this, check that the CV readings in your JSON file have valid numbers

---

## Next Steps

Once you have clean trajectories from the **Decoupled EKF**:

1. **Tune Parameters:** Adjust `camera_noise_pos` in `app/filter.py` to optimize the balance between responsiveness and smoothness
2. **Test Different Motions:** Record different sketching patterns (circles, lines, 3D spirals) to validate the EKF across various scenarios
3. **Deploy to Live System:** Once satisfied with offline results, integrate the decoupled EKF into your live application

---

## Summary of Changes

### What Was Fixed:
- **One-Euro Filter Integration:** The filter is now applied during recording, not as a post-processing step
- **Timestamp Handling:** Fixed the NaN issue caused by improper filter initialization
- **Simplified Workflow:** No need for separate post-processing scripts

### What You Should Use:
- **For Recording:** `python3 record_raw_data_filtered.py`
- **For Analysis:** `python3 compare_workflows.py`

This workflow ensures repeatable, clean results for your EKF development and testing.

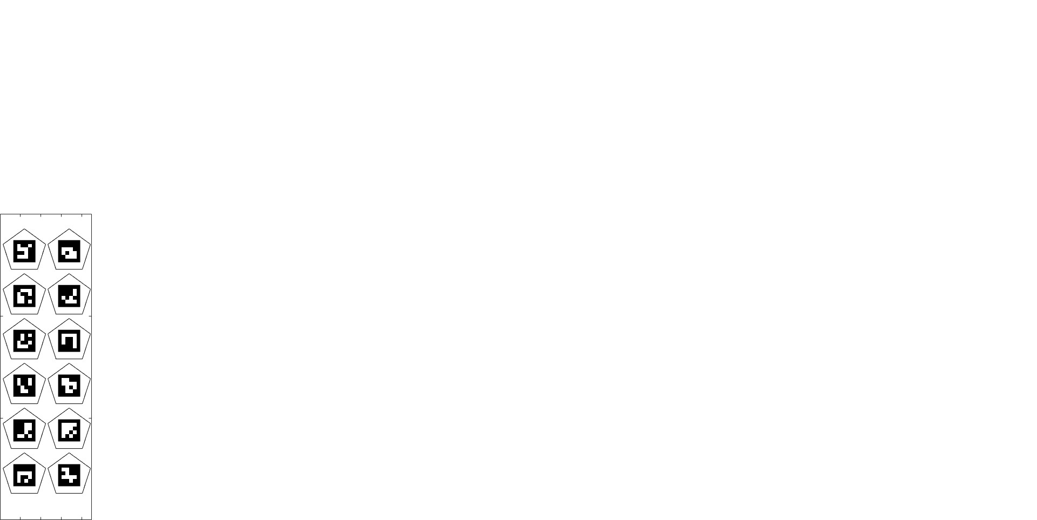
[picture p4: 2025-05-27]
aruco_images/print.jpg

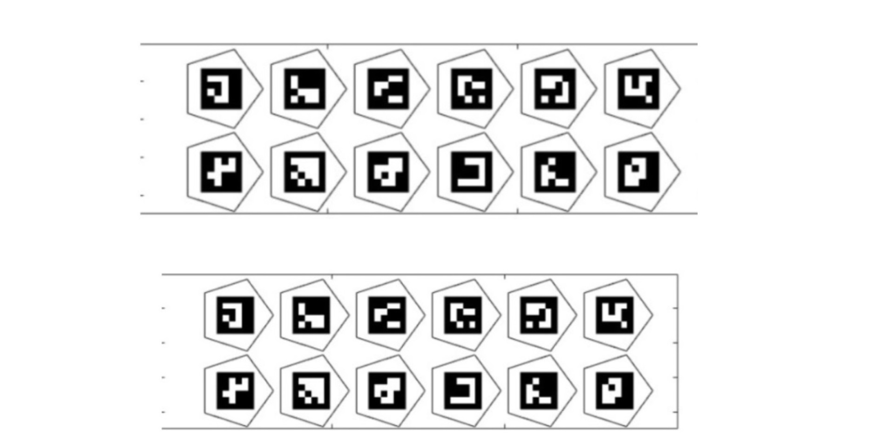
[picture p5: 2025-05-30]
Code/Computer_vision/print.jpg

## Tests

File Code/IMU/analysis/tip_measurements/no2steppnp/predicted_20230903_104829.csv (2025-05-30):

0.000988719 | 0.025962645 | 1.5081755e-05
0.0003994761 | 0.024874503 | -0.00031959818
-5.0939714e-05 | 0.02520879 | -0.00093396544
-0.00061105535 | 0.025585424 | -0.0004126248
0.0006081067 | 0.025196314 | -0.0011514479
-5.0023114e-05 | 0.026214939 | -0.000998219
-0.0011631214 | 0.025433293 | -0.0007946275
-0.0015963342 | 0.024322614 | 0.0003280963
-0.0009729329 | 0.024746282 | -0.0004860177
8.127195e-05 | 0.024458982 | -0.0009467948
-2.3815928e-05 | 0.14483851 | -0.00057031884
0.00033275783 | 0.14404711 | -0.00069739425
0.00021030256 | 0.14434724 | -0.0005502042
-0.00033741855 | 0.14444739 | -0.00045044706
-0.00017841718 | 0.14336857 | -0.0003970959
-0.00019879515 | 0.1433702 | -0.00028272715
-7.8505254e-05 | 0.14329271 | -0.00032725665
0.0009281744 | 0.1466855 | -0.0006902015
0.00079110765 | 0.14337167 | -0.00027919322
-0.00011933327 | 0.14356677 | -0.00014511406
0.0003138622 | 0.26272592 | -0.0006527511
0.0008508221 | 0.26250455 | -0.0011773211
-0.00033299095 | 0.26208067 | -0.000637439
0.001032939 | 0.26248762 | -0.00091222115
0.0006040647 | 0.26181027 | -0.0008861628
-0.00066502753 | 0.2594022 | -0.0012327172
0.0010597635 | 0.26068798 | -0.0006799782
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

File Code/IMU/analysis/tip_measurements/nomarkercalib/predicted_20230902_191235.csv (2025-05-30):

0.0014141263 | 0.024553621 | 5.8834168e-05
0.0023236386 | 0.02523166 | -8.966219e-05
0.0015790227 | 0.026338127 | -0.0005602371
0.00024782165 | 0.025628017 | -0.00014026067
0.00094174786 | 0.025512496 | 6.263566e-05
0.0004122328 | 0.14360198 | 6.1106846e-05
0.00093417586 | 0.14414872 | -0.0002516737
0.0010865261 | 0.14363435 | -0.00031100702
0.0006521406 | 0.14537634 | -2.2045893e-05
0.0015282324 | 0.14462824 | -0.0006252238
-0.00018699863 | 0.1444019 | 0.00024900382
-0.0006599318 | 0.14404143 | 0.0004414377
0.0007905522 | 0.14370933 | -0.00021530614
0.0014647718 | 0.14423636 | -0.00011577799
0.0014899628 | 0.14449194 | -7.174196e-05
0.0009383219 | 0.024725506 | 0.00010030966
0.0013567837 | 0.02567877 | 0.00013983343
-6.125108e-06 | 0.024196347 | -0.00048550405
0.0016938101 | 0.025339687 | -6.674391e-05
-0.0007620022 | 0.026337849 | 0.0004691193
0.00052437466 | 0.2635748 | 2.0806963e-05
0.00069621496 | 0.2642158 | 0.0001255706
0.0007566231 | 0.26430744 | -0.00048155617
0.00046326534 | 0.26376262 | -0.00016481453
-0.00022522412 | 0.26451325 | 0.00019521681
-0.001210059 | 0.26380408 | 0.00024083661
-0.00036001968 | 0.2630329 | -5.96105e-06
0.0010297245 | 0.2633452 | -0.00033040126
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

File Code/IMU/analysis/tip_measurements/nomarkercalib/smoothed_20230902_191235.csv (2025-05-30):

0.0016742414 | 0.024450984 | 5.7748148e-05
0.0018236212 | 0.02506619 | -2.1763663e-05
0.0013008809 | 0.025562134 | -0.0003653401
0.00043026748 | 0.025447594 | -0.00015804893
0.0011996034 | 0.024831023 | -0.00016407818
0.00019753393 | 0.14342597 | -0.00015245653
0.0010958357 | 0.14434528 | -0.00013294857
0.0015905233 | 0.14361745 | -0.00016152325
0.0010257148 | 0.14490484 | -9.178967e-05
0.0014786121 | 0.14416517 | -0.0003871435
-2.3638711e-05 | 0.14406408 | 0.00023682184
-0.00079716014 | 0.14315985 | 0.00028282715
0.0006409988 | 0.14352158 | -0.0002710929
0.0014790358 | 0.14449689 | -0.00020674539
0.0020802314 | 0.14439535 | -3.66339e-05
0.00094449334 | 0.024958648 | -6.465695e-05
0.0018162183 | 0.02506369 | -4.1450796e-05
0.00023790926 | 0.025245018 | -0.0002989177
0.001561813 | 0.024836395 | -0.00011486184
-0.0005173678 | 0.025556246 | 0.0002932321
0.0009506509 | 0.26418257 | -0.000264499
0.00097116426 | 0.26452184 | 3.196023e-05
0.00017269785 | 0.26383412 | -0.0005285385
0.00014483406 | 0.2641118 | -0.00022902
0.0005305559 | 0.26477817 | 0.00014491081
-0.00069827586 | 0.262862 | 0.00018413611
-0.00038334014 | 0.2625968 | -6.1392406e-05
0.00055882183 | 0.2635401 | -0.00037180036
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

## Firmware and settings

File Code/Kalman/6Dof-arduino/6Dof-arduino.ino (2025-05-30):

#include <Adafruit_SPIFlash.h>
#include <LSM6DS3.h>
#include <Wire.h>
#include <bluefruit.h>
#include <nrf52840.h>
#include <nrf_saadc.h>
#include <nrf_power.h>

#define LEDR LED_RED
#define LEDG LED_GREEN
#define LEDB LED_BLUE

#define PRESSURE_SENSOR_VCC_PIN D1
#define PRESSURE_SENSOR_SAADC_CHANNEL 0

const unsigned long delayMs = 7;
const unsigned long rate = 1000/delayMs;
const unsigned long stayAwakeTimeMs = 1000*60;

struct IMUDataPacket {
  int16_t accel[3];
  int16_t gyro[3];
  uint16_t pressure;
};

const uint8_t LBS_UUID_SERVICE[] =
{
  0x19, 0xB1, 0x00, 0x10, 0xE8, 0xF2, 0x53, 0x7E, 0x4F, 0x6C, 0xD1, 0x04, 0x76, 0x8A, 0x12, 0x14
};

// 19B10013-E8F2-537E-4F6C-D104768A1214
const uint8_t LBS_UUID_CHR_IMU[] =
{
  0x14, 0x12, 0x8A, 0x76, 0x04, 0xD1, 0x6C, 0x4F, 0x7E, 0x53, 0xF2, 0xE8, 0x13, 0x00, 0xB1, 0x19
};

BLEService bleService(LBS_UUID_SERVICE);
BLECharacteristic imuCharacteristic(LBS_UUID_CHR_IMU);

Adafruit_FlashTransport_QSPI flashTransport;
LSM6DS3 imu(I2C_MODE, 0x6A); //I2C device address 0x6A

const nrf_saadc_channel_config_t adcConfig = {
  .resistor_p = NRF_SAADC_RESISTOR_DISABLED,
  .resistor_n = NRF_SAADC_RESISTOR_DISABLED,
  .gain       = NRF_SAADC_GAIN4,
  .reference  = NRF_SAADC_REFERENCE_VDD4,
  .acq_time   = NRF_SAADC_ACQTIME_20US,
  .mode       = NRF_SAADC_MODE_DIFFERENTIAL,
  .burst      = NRF_SAADC_BURST_ENABLED,
};

// Disable QSPI flash to save power
void QSPIF_sleep(void)
{
  flashTransport.begin();
  flashTransport.runCommand(0xB9);
  flashTransport.end();
}

void imuISR() {
  // Interrupt triggers for both single and double taps, so we need to check which one it was.
  uint8_t tapSrc;
  status_t status = imu.readRegister(&tapSrc, LSM6DS3_ACC_GYRO_TAP_SRC);
  bool wasDoubleTap = (tapSrc & LSM6DS3_ACC_GYRO_DOUBLE_TAP_EV_STATUS_DETECTED) > 0;
  if (!wasDoubleTap) {
    nrf_power_system_off(NRF_POWER);
  }
}

void setupWakeUpInterrupt()
{
  // Tap interrupt code is based on code by daCoder
  // https://forum.seeedstudio.com/t/xiao-sense-accelerometer-examples-and-low-power/270801
  imu.settings.gyroEnabled = 0;
  imu.settings.accelEnabled = 1;
  imu.settings.accelSampleRate = 104;
  imu.settings.accelRange = 2;
  imu.begin();

  //https://www.st.com/resource/en/datasheet/lsm6ds3tr-c.pdf
  imu.writeRegister(LSM6DS3_ACC_GYRO_TAP_CFG1, 0b10001000); // Enable interrupts and tap detection on X-axis
  imu.writeRegister(LSM6DS3_ACC_GYRO_TAP_THS_6D, 0b10001000); // Set tap threshold
  const int duration = 0b0010 << 4; // 1LSB corresponds to 32*ODR_XL time
  const int quietTime = 0b10 << 2; // 1LSB corresponds to 4*ODR_XL time
  const int shockTime = 0b01 << 0; // 1LSB corresponds to 8*ODR_XL time
  imu.writeRegister(LSM6DS3_ACC_GYRO_INT_DUR2, duration | quietTime | shockTime); // Set Duration, Quiet and Shock time windows
  imu.writeRegister(LSM6DS3_ACC_GYRO_WAKE_UP_THS, 0x80); // Single & double-tap enabled (SINGLE_DOUBLE_TAP = 1)
  imu.writeRegister(LSM6DS3_ACC_GYRO_MD1_CFG, 0x08); // Double-tap interrupt driven to INT1 pin
  imu.writeRegister(LSM6DS3_ACC_GYRO_CTRL6_G, 0x10); // High-performance operating mode disabled for accelerometer

  // Set up the sense mechanism to generate the DETECT signal to wake from system_off
  pinMode(PIN_LSM6DS3TR_C_INT1, INPUT_PULLDOWN_SENSE);
  attachInterrupt(digitalPinToInterrupt(PIN_LSM6DS3TR_C_INT1), imuISR, CHANGE);

  return;
}

void setupPressureSensor() {
  pinMode(PRESSURE_SENSOR_VCC_PIN, OUTPUT);
  digitalWrite(PRESSURE_SENSOR_VCC_PIN, HIGH);

  nrf_saadc_enable(NRF_SAADC);

  nrf_saadc_oversample_set(NRF_SAADC, NRF_SAADC_OVERSAMPLE_32X);
  nrf_saadc_resolution_set(NRF_SAADC, NRF_SAADC_RESOLUTION_12BIT);
  nrf_saadc_channel_input_set(NRF_SAADC, PRESSURE_SENSOR_SAADC_CHANNEL, NRF_SAADC_INPUT_AIN2, NRF_SAADC_INPUT_AIN4);
  nrf_saadc_channel_init(NRF_SAADC, PRESSURE_SENSOR_SAADC_CHANNEL, &adcConfig);

  NRF_SAADC->TASKS_CALIBRATEOFFSET = 1;
  while (NRF_SAADC->EVENTS_CALIBRATEDONE == 0);
  NRF_SAADC->EVENTS_CALIBRATEDONE = 0;
  while (NRF_SAADC->STATUS == (SAADC_STATUS_STATUS_Busy << SAADC_STATUS_STATUS_Pos));

  nrf_saadc_disable(NRF_SAADC);
}

int16_t readPressure() {
  volatile nrf_saadc_value_t result = -1;

  nrf_saadc_enable(NRF_SAADC);
  nrf_saadc_continuous_mode_disable(NRF_SAADC);

  NRF_SAADC->RESULT.MAXCNT = 1;
  NRF_SAADC->RESULT.PTR = (uint32_t)&result;

  // Start the SAADC and wait for the started event.
  NRF_SAADC->TASKS_START = 1;
  while (NRF_SAADC->EVENTS_STARTED == 0);
  NRF_SAADC->EVENTS_STARTED = 0;

  // Do a SAADC sample, will put the result in the configured RAM buffer.
  NRF_SAADC->TASKS_SAMPLE = 1;
  while (NRF_SAADC->EVENTS_END == 0);
  NRF_SAADC->EVENTS_END = 0;

  NRF_SAADC->TASKS_STOP = 1;
  while (NRF_SAADC->EVENTS_STOPPED == 0);
  NRF_SAADC->EVENTS_STOPPED = 0;

  nrf_saadc_disable(NRF_SAADC);

  // Scaling to match previous mbed implementation
  return int16_t((uint32_t(result) * 0xFFFF) / 0x0FFF);
}

void setupImu() {
  imu.settings.accelRange = 4; // Can be: 2, 4, 8, 16
  imu.settings.gyroRange = 500; // Can be: 125, 245, 500, 1000, 2000
  imu.settings.accelSampleRate = 416; //Hz.  Can be: 13, 26, 52, 104, 208, 416, 833, 1666, 3332, 6664, 13330
  imu.settings.gyroSampleRate = 416; //Hz.  Can be: 13, 26, 52, 104, 208, 416, 833, 1666
  imu.settings.accelBandWidth = 200;
  imu.settings.gyroBandWidth = 200;
  imu.begin();
}

void runBle() {
  // Serial.println("before while loop");
  while (Bluefruit.connected(0)) {
    unsigned long startTime = millis();

    IMUDataPacket packet;
    // This could be optimised by reading all values as a block.
    packet.accel[0] = imu.readRawAccelX();
    packet.accel[1] = imu.readRawAccelY();
    packet.accel[2] = imu.readRawAccelZ();
    packet.gyro[0] = imu.readRawGyroX();
    packet.gyro[1] = imu.readRawGyroY();
    packet.gyro[2] = imu.readRawGyroZ();

    packet.pressure = readPressure();
    // Serial.println("PRESSURE IS: "+packet.pressure);
    
    imuCharacteristic.notify(&packet, sizeof(packet));

    // Inaccurate but usable way to throttle the rate of measurements.
    unsigned long time = millis() - startTime;
    unsigned long waitPeriod = delayMs - time;
    if (waitPeriod > 0 && waitPeriod < 500) { // protection against overflow issues
      delay(waitPeriod);
    }
  }
}

void startAdvertising()
{
  Bluefruit.Advertising.addFlags(BLE_GAP_ADV_FLAGS_LE_ONLY_GENERAL_DISC_MODE);
  Bluefruit.Advertising.addTxPower();
  Bluefruit.Advertising.addService(bleService);

  Bluefruit.ScanResponse.addName();
  
  Bluefruit.Advertising.restartOnDisconnect(true);
  Bluefruit.Advertising.setInterval(128, 488);    // in unit of 0.625 ms
  Bluefruit.Advertising.setFastTimeout(30);      // number of seconds in fast mode
  Bluefruit.Advertising.start(0);                // 0 = Don't stop advertising after n seconds
}

void sleepUntilDoubleTap() {
  digitalWrite(LEDR, HIGH);
  digitalWrite(LEDG, HIGH);
  digitalWrite(LEDB, HIGH);

  Serial.println("Setting up interrupt");
  // Setup up double tap interrupt to wake back up
  setupWakeUpInterrupt();

  Serial.println("Entering sleep");
  Serial.flush();

  //Execution should not go beyond this
  nrf_power_system_off(NRF_POWER);
}

void setup() {
  Serial.begin(9600);
  while (!Serial && millis() < 1000); // Timeout in case serial disconnected.
  pinMode(LEDR, OUTPUT);
  pinMode(LEDG, OUTPUT);
  pinMode(LEDB, OUTPUT);
  digitalWrite(LEDR, LOW);
  digitalWrite(LEDG, HIGH);
  digitalWrite(LEDB, HIGH);
  QSPIF_sleep();

  Bluefruit.autoConnLed(false);
  Serial.println("Initialise the Bluefruit nRF52 module");
  Bluefruit.configPrphBandwidth(4); // max is BANDWIDTH_MAX = 4
  Serial.print("Begin Bluefruit: ");
  Serial.println(Bluefruit.begin(1, 0));
  Bluefruit.Periph.setConnInterval(6, 6);
  Bluefruit.setName("DPOINT");
  Serial.println("Begin bleService");
  bleService.begin();

  imuCharacteristic.setProperties(CHR_PROPS_READ | CHR_PROPS_NOTIFY);
  imuCharacteristic.setPermission(SECMODE_OPEN, SECMODE_NO_ACCESS);
  imuCharacteristic.setFixedLen(sizeof(IMUDataPacket));
  // Serial.println("Begin imuCharacteristic");
  imuCharacteristic.begin();
  IMUDataPacket initialPacket = { 0 };
  imuCharacteristic.write(&initialPacket, sizeof(initialPacket));

  Serial.println("Setup finished");
}

void loop() {
  Serial.println("Starting advertising...");
  startAdvertising();
  digitalWrite(LEDR, HIGH);
  digitalWrite(LEDG, HIGH);
  digitalWrite(LEDB, LOW);

  // Serial.print("Starting IMU...");
  setupImu();

  unsigned long wakeUpTime = millis();

  while (millis() - wakeUpTime < stayAwakeTimeMs) {
    if (Bluefruit.connected(0)) {
      Serial.println("Connected");
      setupPressureSensor();
      digitalWrite(LEDR, HIGH);
      digitalWrite(LEDG, LOW);
      digitalWrite(LEDB, HIGH);
      Serial.println("before runBle");
      runBle();
      Serial.println("after runBle");
      digitalWrite(LEDR, HIGH);
      digitalWrite(LEDG, HIGH);
      digitalWrite(LEDB, LOW);
      digitalWrite(PRESSURE_SENSOR_VCC_PIN, LOW);
      wakeUpTime = millis();
    }
    // Don't sleep if USB connected, to make code upload easier.
    if (Serial) wakeUpTime = millis();
    delay(100);
  }
  Serial.println("Stopping advertising");
  Bluefruit.Advertising.stop();
  sleepUntilDoubleTap();
}

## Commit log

2025-05-25 Added STL files for 3D printing stylus
    [01_stylus_half.stl, 02_nib_holder.stl, 03_nib_base.stl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]
2025-05-27 added CAD files and ArUco markers
2025-05-30 updated stylus CAD
2025-05-30 removed STL folder
    [01_stylus_half.stl, 02_nib_holder.stl, 03_nib_base.stl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]
2025-05-30 added computer vision code and IMU code, before merging
    [latencies.csv, pen.blend, pen.obj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]
2025-05-30 Added Kalman filter code
2025-09-01 More Computer Vision stuff
    - added pentip calibration
    - added offline video processing
2025-09-23 Added Camera Calibration code
    - added camera calibration code
    - modified readme
2025-10-20 CV-IMU data bridge
    Integrate CV-IMU fusion with dodeca_bridge and EKF link (working Bridge OK test)
    [pen.blend, pen.obj]
2025-10-28 visualize smoothed pen tip
    - added visualization of pen tip in CV window in run.py
    - added exception handling for exiting all threads gracefully when pressing 'q' to exit CV window
2025-10-28 enhanced visualization
    - added visualization for difference between raw and smoothed pen tip position using Euclidean norm
    Things to improve:
    - in filter.py, play with EKF's variables to improve accuracy
    - recalibrate and capture better tip_offset_body transformation
2026-01-19 Implement CV-only mode, offline video support, and trajectory plotting
    [trajectory.csv]
2026-01-19 new offline video
    [trajectory.csv]
2026-01-25 fix QThread termination and optimize CV-only trajectory smoothness
    - Fix QThread/QEventLoop error by ensuring a QApplication instance exists in headless mode.
    - Improve shutdown sequence in app.py to gracefully wait for CV thread completion.
    - Reduce trajectory jitter by adding sub-pixel corner refinement in Tracker.py.
    - Re-tune EKF parameters in filter.py to favor smooth motion over noisy CV measurements.
    - Increase smoothing buffer length and tune blending alpha for a more stable path.
    [trajectory.csv]
2026-01-26 Restore live camera + BLE mode: cv_only now properly toggles between offline video and live camera+IMU
2026-02-08 Update trajectory output paths to outputs folder and add workflow comparison visualizations
    [playback_trajectory.csv]
2026-02-10 Add trajectory cleaning and visualization script with filtered results
    [clean_trajectory.csv]
2026-02-10 Revert trajectory cleaning changes
    [clean_trajectory.csv]
2026-02-10 Add hybrid recording workflow: separate video CV processing and IMU recording with sync
2026-02-11 Revert hybrid workflow - switching to simpler One-Euro filter post-processing
2026-02-11 Add filtered recording with integrated One-Euro filter for clean CV data
2026-02-11 Fix CV recording thread and asyncio compatibility for stable data capture
2026-02-11 Remove separate playback/plot workflow (playback_raw_data.py, plot_trajectory.py) and associated outputs
    [playback_trajectory.csv, trajectory.csv]
2026-02-11 Fix coordinate system naming: IMU_TO_TIP_BODY -> IMU_OFFSET_BODY, TIP_OFFSET_BODY -> CENTER_TO_TIP_BODY, imu_pos_cam -> center_pos_cam
    - Renamed IMU_TO_TIP_BODY to IMU_OFFSET_BODY (offset from dodeca center to IMU)
    - Renamed TIP_OFFSET_BODY to CENTER_TO_TIP_BODY (more explicit)
    - Renamed imu_pos_cam to center_pos_cam (what CV actually detects)
    - Added comprehensive coordinate system documentation in dodeca_bridge.py
    - Updated all recording, comparison, and filter code with corrected names
    - Added backward compatibility in compare_workflows.py for old JSON files
    - Updated RECORDING_WORKFLOW_GUIDE.md with coordinate system explanation
    - Resolved merge conflicts in compare_workflows.py
    This fi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
2026-02-18 Optimize EKF parameters and fix IMU-to-Camera coordinate mapping
2026-02-18 added sample run
2026-03-03 Fix: Allow negative timestamps and add trajectory points for EKF workflows
    - Removed skip of negative timestamps to allow IMU warmup before CV detection
    - Added trajectory point generation after CV updates for Standard and Decoupled EKF modes
    - Improved CV Only visibility in plots (blue dotted line)
    - Fixes issue where EKF workflows only showed 1 point when IMU data preceded CV data
2026-03-03 Implement IMU Sensor Timestamp as Master Clock for deterministic CV-IMU synchronization
2026-03-06 Add backwards compatibility for 14-byte legacy IMU packets in BLE handler
2026-03-08 Add offline IMU plotting script with Kalman Filter
2026-03-08 Add gyro bias correction and acceleration plots to offline IMU processing
    - Fix hardcoded Linux paths to use cross-platform relative paths
    - Add gyro Z-axis bias correction (GZ_BIAS = -0.018 rad/s) to reduce yaw drift
    - Add acceleration X/Y/Z component plotting in 4th subplot
    - Add error handling for empty IMU readings
    - Initialize Kalman filter state from first accelerometer reading
2026-03-27 Add IMU-body alignment calibration and EKF gravity fit
